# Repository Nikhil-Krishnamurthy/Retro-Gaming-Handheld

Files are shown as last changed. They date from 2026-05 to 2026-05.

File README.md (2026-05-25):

# Retro-Gaming-Handheld
This project was creating a gaming handheld from scratch, including cadding the case and designing the pcb. This handheld will run retro games up to the SNES.

Key Features
Esp32 powered emulation   
RGB444 7in screen    
Dedicated sound system    
Cold swappable storage system    
Rechargable 3500mAh battery    
USB C data transfer to computer    
USB C powered charging    

Schematic   

Power   


Buttons   


Screen   


Data   


Sound   


ESP 32   


PCB Layout   


Case   




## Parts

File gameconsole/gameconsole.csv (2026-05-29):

Reference | Qty | Value | DNP | Exclude from BOM | Exclude from Board | Footprint | Datasheet | Description_1 | MP
A_Button1,B_Button1,DOWN1,LEFT1,MENU1,RIGHT1,SELECT_Button1,START_Button1,SW1,SW2,UP1,X_Button1,Y_Button1 | 13 | PTS810 (250gf) |  |  |  | PTS810_SJM_250_SMTR_LFS:SW_PTS810_SJM_250_SMTR_LFS |  | Tactile Switch, SPST-NO, Top Actuated, Surface Mount (SMT), 2.5mm height, 0.15mm travel. Local equivalent OK, but must match footprint dimensions, SMT pad style, 160gf to 260gf of activiation force | PTS810_SJM_250_SMTR_LFS
C1,C3,C5,C8,C14,C15,C17,C19 | 8 | 10uF |  |  |  | CL31A106MBHNNNE:CAPC3216X180N |  | 10uF, 16V or higher, X7R, 1206
C2,C9,C10,C11,C12,C13,C16,C23,C24,C29 | 10 | 10nF |  |  |  | GRM1885C1H103JA01D:CAPC1608X90N |  | 10nF, 16V or higher, X7R, 0805
C4,C7,C20 | 3 | 100nF |  |  |  | CL10B104KB8NNNC:CAPC1608X90N |  | 100nF, 16V or higher, X7R, 0805
C6 | 1 | 0.47uF |  |  |  | CL10B474KA8NFNC:CAPC1608X90N |  | 0.47uF, 16V or higher, X7R, 0805
C18 | 1 | 0.047uF |  |  |  | Capacitor_SMD:C_0805_2012Metric_Pad1.18x1.45mm_HandSolder |  | 0.047uF, 16V or higher, X7R, 0805
C21,C22 | 2 | 4.7uF |  |  |  | CL31B475KAHNNNE:CAPC3216X180N |  | 4.7uF, 16V or higher, X7R, 1206
C25,C26 | 2 | 47uF |  |  |  | C3216X5R1E476M160AC:CAPC3216X180N |  | 47uF, 16V or higher, X5R, 1206
C27 | 1 | 1000pF |  |  |  | Capacitor_SMD:C_0805_2012Metric_Pad1.18x1.45mm_HandSolder |  | 1000pF, 16V or higher, C0G, 0805
C28 | 1 | 47pF |  |  |  | Capacitor_SMD:C_0805_2012Metric_Pad1.18x1.45mm_HandSolder |  | 47pF, 16v or higher, C0G, 0805
D1 | 1 | MBR0520LT1G |  |  |  | MBR0520LT1G:SOD3716X135N |  | Local Equivalent OK. Diode Schottky 20 V 500mA Surface Mount SOD-123 | MBR0520LT1G
D2 | 1 | B340A |  |  |  | B340AE-13:DIOM5226X230N |  | Local Equivalent OK. Must be SMA package. | B340AE-13
IHLP1616BZER4R7M11 | 1 | 4.7uH |  |  |  | ul_IHLP1616BZER4R7M11:IND_IHLP-1616BZ_VIS |  | Local Equivalent OK, 4.7uH, 20% tolerance or higher, 1.75 lsat, shielded | IHLP1616BZER4R7M11
J1 | 1 | 62684-401100ALF |  |  |  | 62684-401100ALF:CONN_62684-401100ALF_AMP | 62684-401100ALF | Local Equivalent OK, bottom contacts, 40 position, 0.50mm pitch | 62684-401100ALF
J2 | 1 | USB4216-03-A_REVA |  |  |  | USB4216-03-A_REVA:GCT_USB4216-03-A_REVA |  | Type C USB 2.0 Connector | USB4216-03-A
L2 | 1 | WE-MAPI_2512 |  |  |  | WE-MAPI_4020:WE-MAPI_4020 |  | WE-MAPI SMD Power Inductor 1.5uH 2.2A | Wurth Electronics 74438324015, local equivilent OK as long as electrical aspects and footprints are exactly the same | 74438324015
L3 | 1 | 6.8uH |  |  |  | LIB_BMRA000606306R8MA1:INDPM7366X300N |  | Shielded Molded Power Inductor, 6.8uH, ±20%, 4.5A Irms, 8.0A Isat, 60mOhm max DCR, SMD, 7.3mm x 6.6mm x 3.0mm. Local equivalent OK if all electrical and footprint dimensions match exactly. | BMRA000606306R8MA1
L_Button1,R_Button1,SW3,VOLDWN1,VOLUP1 | 5 | SW_Push |  |  |  | TL3330AF130QG:SW_TL3330AF130QG |  | Local Equivilent OK, 0.25mm switch travel, Right angle mount, SPST-NO, Gull Wing Leads, 130gf operating force
R1,R4,R5,R7,R8,R9,R10,R11,R12,R14,R17,R18,R19,R20,R30,R31,R32,R33,R34,R35,R36,R37,R38,R39,R40,R41,R43,R44,R45,R46,R47 | 31 | 10k |  |  |  | Resistor_SMD:R_0805_2012Metric_Pad1.20x1.40mm_HandSolder |  | 10k, 5% or tighter, 1/8W or higher, 0805
R2,R3 | 2 | EXB-2HV330JV |  |  |  | EXB-2HV330JV:RESCAXE50P380X160X55-16N | EXB-2HV330JV | Thick Film Resistor Array, 33 Ohm, ±5%, 8 Resistors (Isolated Circuit), 16-Pins, Convex Long Side Terminals, 62.5mW per element, 1506 package (3.80mm x 1.60mm). Local equivalent OK but must match footprint, pitch, and isolated circuit structure exactly. | EXB-2HV330JV
R6 | 1 | 1.43 |  |  |  | Resistor_SMD:R_0805_2012Metric_Pad1.20x1.40mm_HandSolder |  | 1.43, 1% or tighter, 1/8W or higher, 0805
R13 | 1 | 634k |  |  |  | Resistor_SMD:R_0805_2012Metric_Pad1.20x1.40mm_HandSolder |  | 634k, 1% or tighter, 1/8W or higher, 0805
R15,R16 | 2 | 5.1k |  |  |  | Resistor_SMD:R_0805_2012Metric_Pad1.20x1.40mm_HandSolder |  | 5.1k, 5% or tighter, 1/8W or higher, 0805
R21 | 1 | 240 |  |  |  | Resistor_SMD:R_0805_2012Metric_Pad1.20x1.40mm_HandSolder |  | 240, 1% or tighter, 1/8W or higher, 0805
R22 | 1 | 5.21K |  |  |  | Resistor_SMD:R_0805_2012Metric_Pad1.20x1.40mm_HandSolder |  | 5.21k, 1% or tighter, 1/8W or higher, 0805
R23 | 1 | 29.87k |  |  |  | Resistor_SMD:R_0805_2012Metric_Pad1.20x1.40mm_HandSolder |  | 29.87k, 1% or tighter, 1/8W or higher, 0805
R24 | 1 | 165k |  |  |  | Resistor_SMD:R_0805_2012Metric_Pad1.20x1.40mm_HandSolder |  | 165k, 5% or tighter, 1/8W or higher, 0805
R25 | 1 | 60.4k |  |  |  | Resistor_SMD:R_0805_2012Metric_Pad1.20x1.40mm_HandSolder |  | 60.4k, 5% or tighter, 1/8W or higher, 0805
R26 | 1 | 0 |  |  |  | Resistor_SMD:R_0805_2012Metric_Pad1.20x1.40mm_HandSolder |  | Resistor, 0 Ohm Jumper, 2A minimum current rating, 0805
R27 | 1 | 10.2k |  |  |  | Resistor_SMD:R_0805_2012Metric_Pad1.20x1.40mm_HandSolder |  | 10.2k, 1% or tighter, 1/8W or higher, 0805
R28 | 1 | 3.24k |  |  |  | Resistor_SMD:R_0805_2012Metric_Pad1.20x1.40mm_HandSolder |  | 3.24k, 1% or tighter, 1/8W or higher, 0805
R29 | 1 | 29.4k |  |  |  | Resistor_SMD:R_0805_2012Metric_Pad1.20x1.40mm_HandSolder |  | 29.4k, 1% or tighter, 1/8W or higher, 0805
U1 | 1 | ESP32-S3-WROOM-1 |  |  |  | RF_Module:ESP32-S3-WROOM-1 | https://www.espressif.com/sites/default/files/documentation/esp32-s3-wroom-1_wroom-1u_datasheet_en.pdf | Wi-Fi + BT 5.0 Module, ESP32-S3 chip, 16MB Quad SPI Flash, 8MB Octal SPI PSRAM, PCB Antenna. Must be exact MPN, no substitutions. | ESP32-S3-WROOM-1-N16R8
U2 | 1 | BQ25895RTWR |  |  |  | BQ25895RTWR:QFN50P400X400X80-25N |  | I2C 1cell 5A buck battery charger with high input voltage and 3.1-A boost with HVDCP enabled | BQ25895RTWR
U3 | 1 | MP3302DJ-LF-Z |  |  |  | MP3302DJ-LF-Z:TSOT23-5_3x3x1p7_MNP | https://www.monolithicpower.com/en/documentview/productdocument/index/version/2/document_type/Datasheet/lang/en/sku/MP3302 | Step-Up Boost Converter, LED Backlight Driver, 200mV Feedback Reference Voltage, 1.33A Switch Current Limit, TSOT-23-5. Local Equivalent OK but must match pinning and 200mV FB reference voltage exactly. | MP3302DJ-LF-Z
U4 | 1 | TCA6424ARGJR |  |  |  | TCA6424ARGJR:QFN50P500X500X60-33N |  | 24-bit translating 1.65- to 5.5-V I2C/SMBus I/O expander with interrupt, reset & config registers | TCA6424ARGJR
U5 | 1 | MAX98357AETE_T |  |  |  | MAX98357AETE_T:QFN50P300X300X80-17N |  | Tiny, Low-Cost, PCM Class D Amplifier with Class AB Performance | MAX98357AETE+T
U7 | 1 | TPS54331DR |  |  |  | TPS54331DR:SOIC127P599X175-8N |  | 3.5V to 28V Input, 3A, 570kHz Step-Down Converter with Eco-mode | TPS54331DR
J3 | 1 | NTCLE413E2103F520L | DNP |  | Excluded from board | S2B-PH-K-S_LF__SN_:JST_S2B-PH-K-S_LF__SN_
J4 | 1 | S2B-PH-K-S_LF__SN_ | DNP |  | Excluded from board | S2B-PH-K-S_LF__SN_:JST_S2B-PH-K-S_LF__SN_ |  | Connector Header Through Hole, Right Angle 2 position 0.079 (2.00mm) | S2B-PH-K-S (LF)(SN)
J5 | 1 | S2B-XH-A_LF__SN_ | DNP |  | Excluded from board | S2B-XH-A_LF__SN_:JST_S2B-XH-A_LF__SN_ |  | Connector Header Through Hole, Right Angle 2 position 0.098 (2.50mm) | S2B-XH-A (LF)(SN)
SDREADER1 | 1 | Conn_01x07_Pin | DNP |  | Excluded from board | Connector_PinHeader_2.54mm:PinHeader_1x07_P2.54mm_Vertical

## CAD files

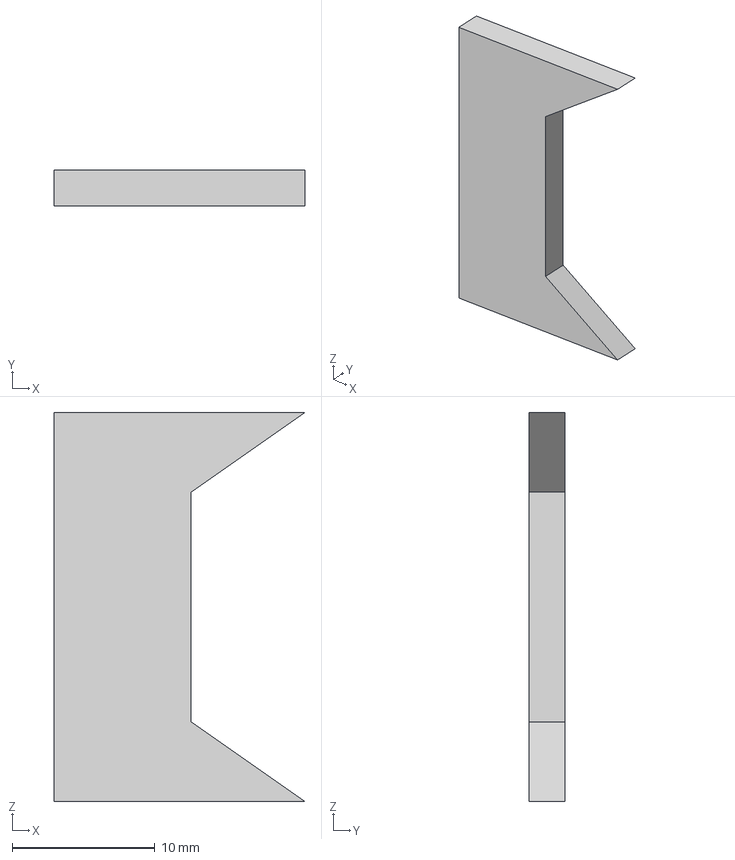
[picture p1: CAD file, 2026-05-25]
CAD/Case/topRightJoint.step
17.6 x 2.50 x 27.3 mm

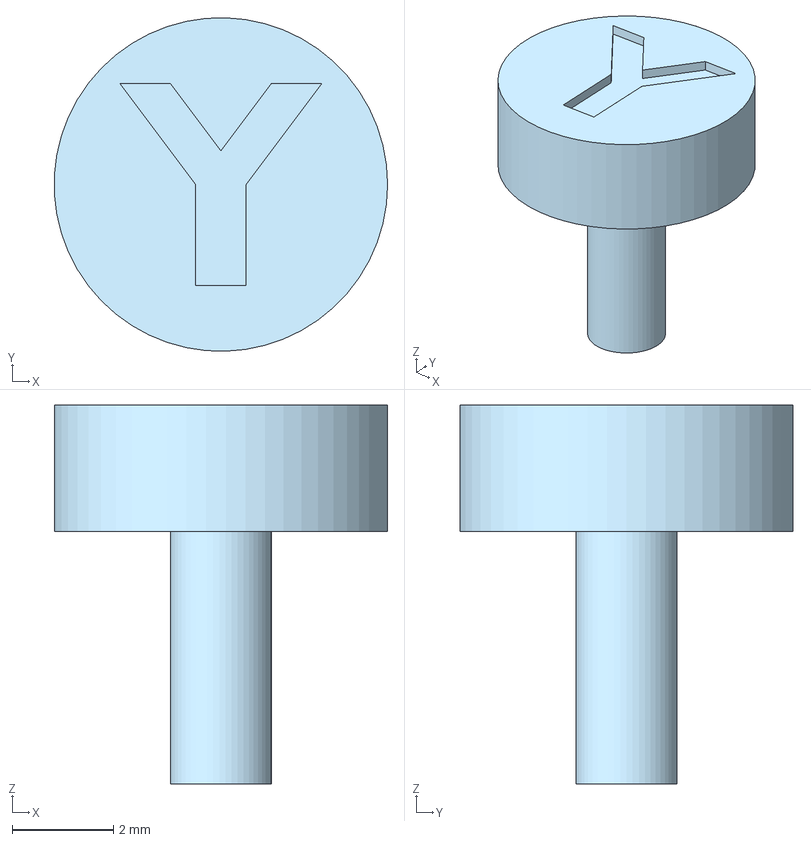
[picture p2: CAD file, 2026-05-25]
CAD/FrontButtons/YCap.step
6.59 x 6.60 x 7.50 mm

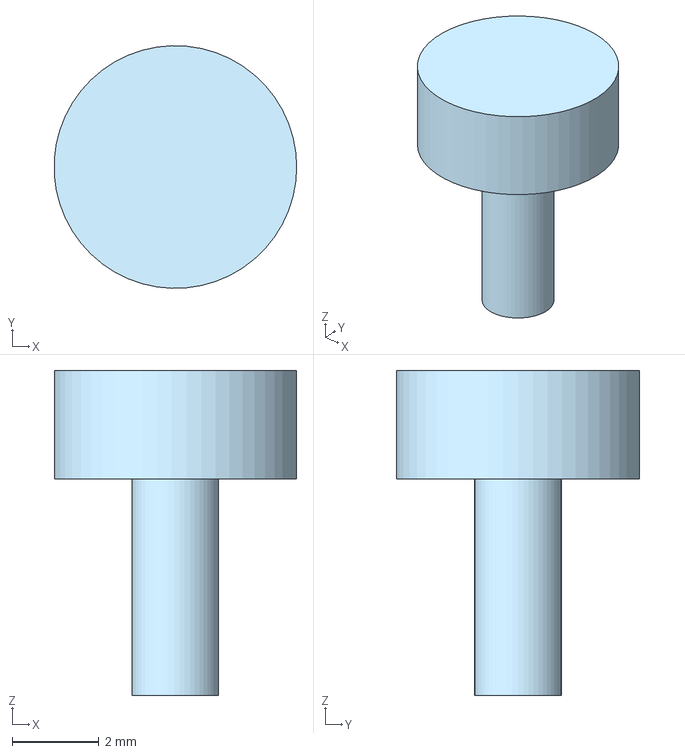
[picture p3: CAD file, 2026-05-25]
CAD/MenuButtons/MenuButtonCap.step
5.59 x 5.60 x 7.50 mm

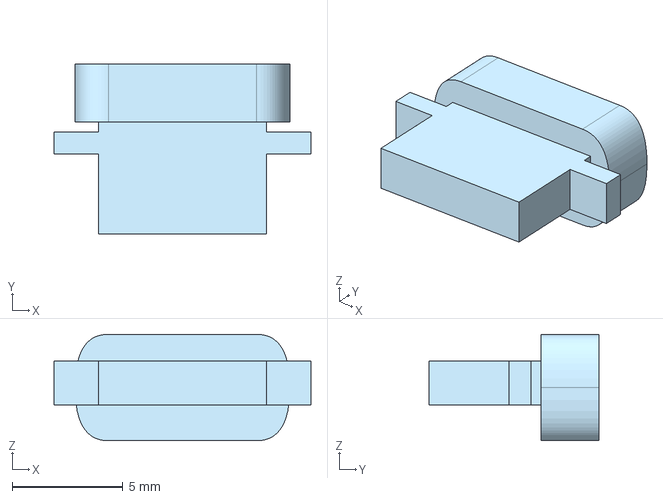
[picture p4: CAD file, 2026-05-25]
CAD/SideButtons/SidePlunger.step
11.6 x 7.68 x 4.80 mm

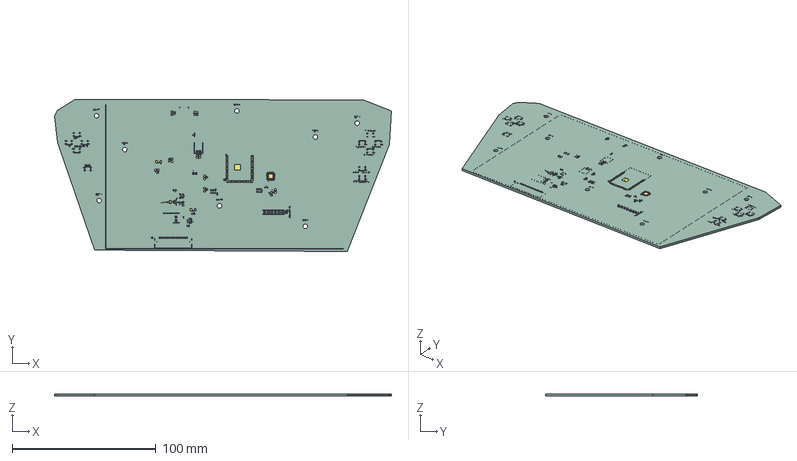
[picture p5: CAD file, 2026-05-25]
gameconsole/case.step
234.1 x 105.6 x 1.66 mm
GameConsoleTransportv2_pad
GameConsoleTransportv2_silkscreen x 2
GameConsoleTransportv2_PCB

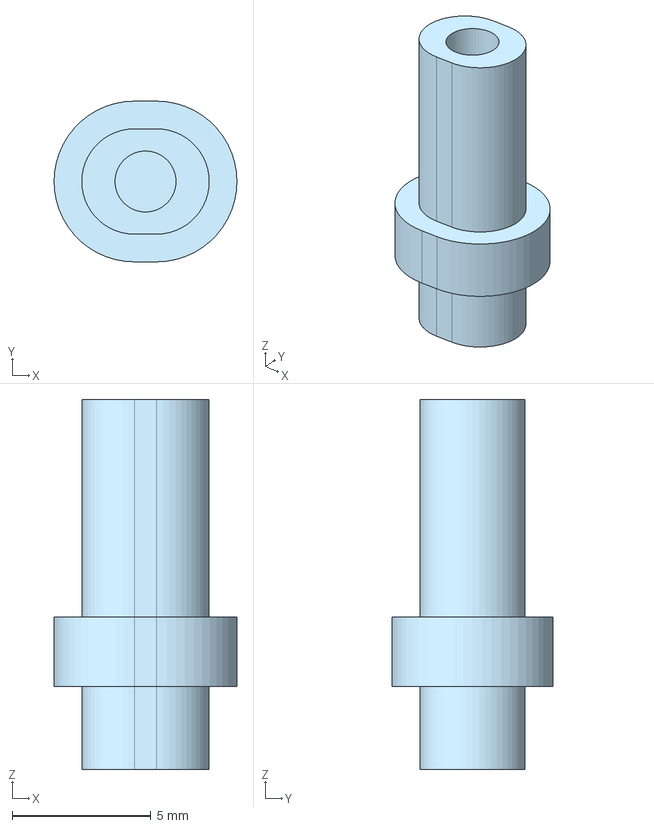
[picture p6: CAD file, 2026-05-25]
CAD/MenuButtons/MenuButtonShaft.step
6.60 x 5.80 x 13.4 mm

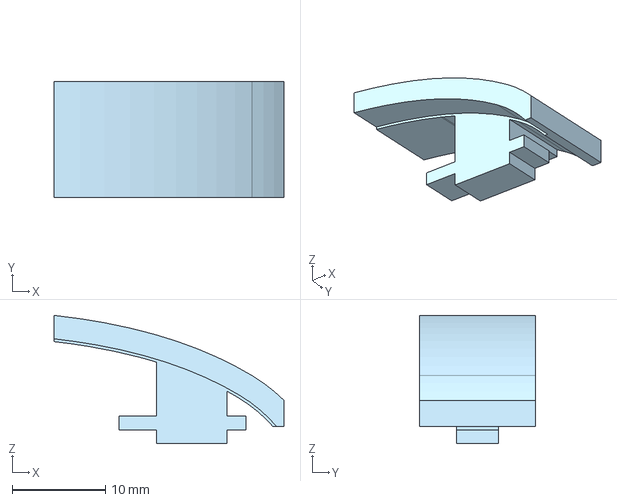
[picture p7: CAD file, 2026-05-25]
CAD/SideButtons/RightPlunger.step
24.7 x 12.5 x 13.8 mm

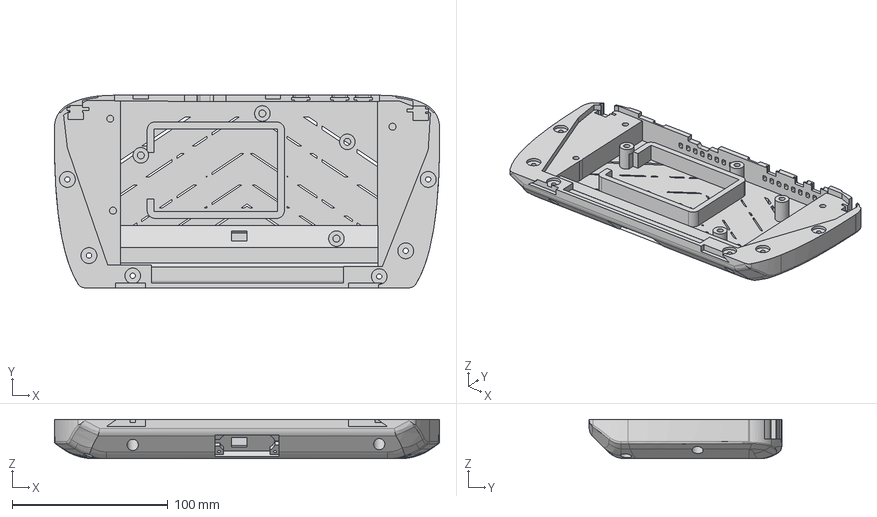
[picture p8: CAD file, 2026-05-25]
CAD/Case/backPanel.step
246.9 x 123.5 x 25.3 mm

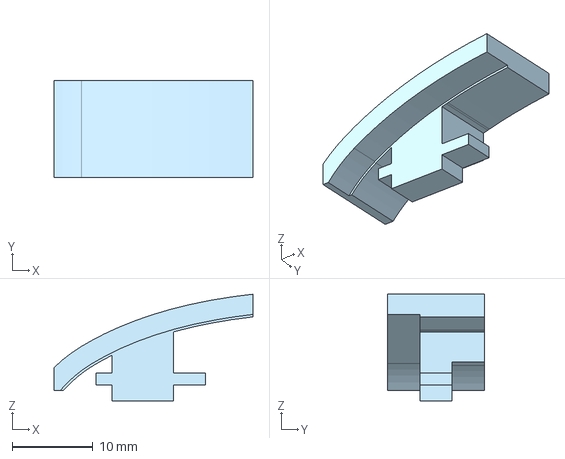
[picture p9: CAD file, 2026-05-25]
CAD/SideButtons/LeftPlunger.step
24.7 x 12.0 x 13.2 mm

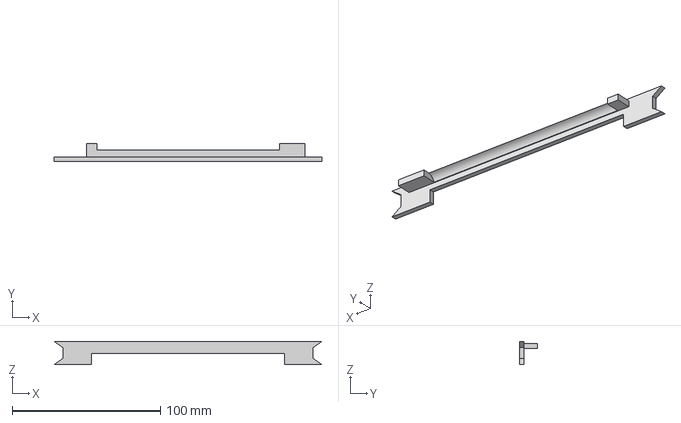
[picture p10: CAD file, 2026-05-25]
CAD/Case/bottomJoint.step
180.6 x 12.1 x 15.7 mm

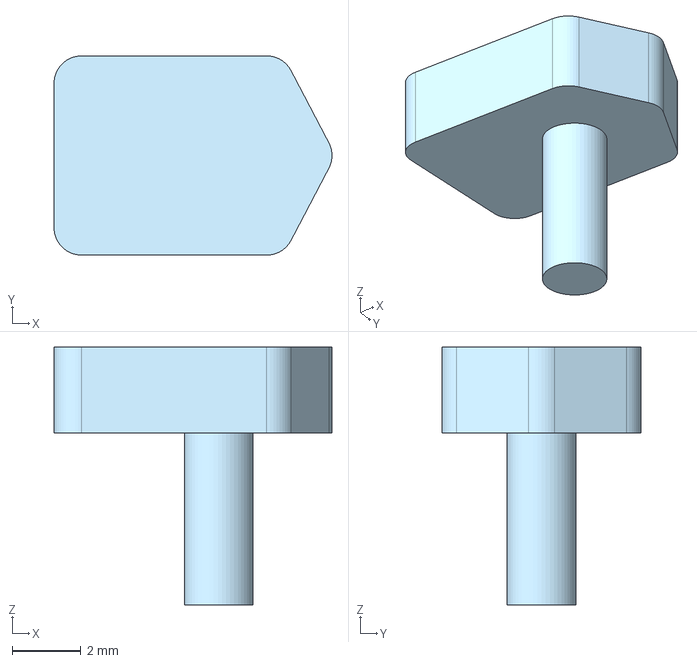
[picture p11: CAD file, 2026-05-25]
CAD/FrontButtons/DPADCap.step
8.10 x 5.80 x 7.50 mm

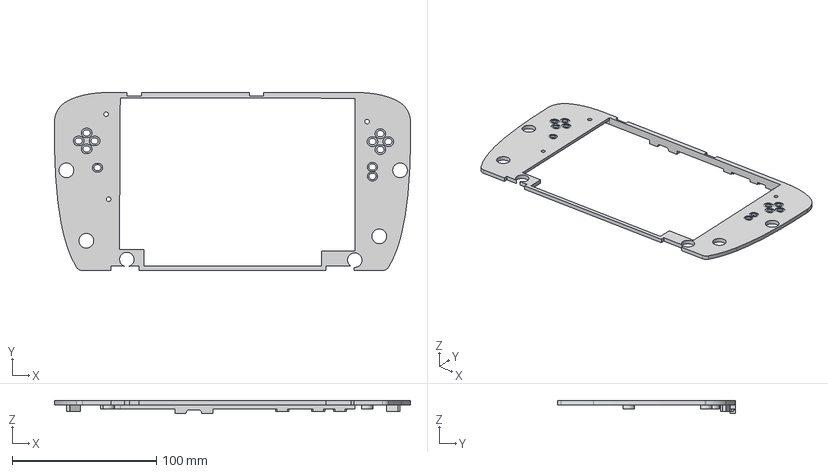
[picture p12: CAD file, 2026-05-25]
CAD/Case/middlePanel.step
246.9 x 123.5 x 8.93 mm

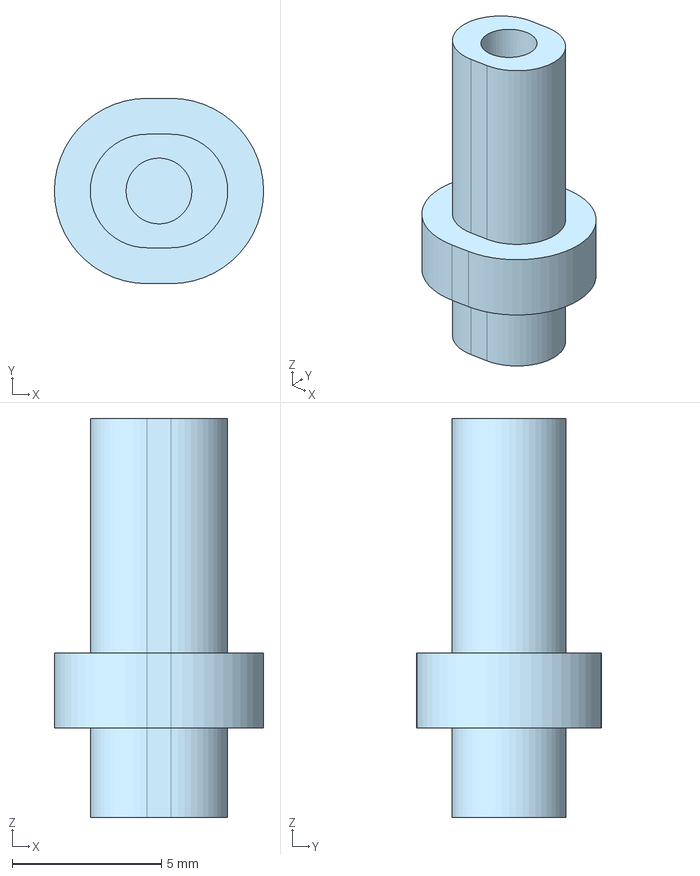
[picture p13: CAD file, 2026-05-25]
CAD/FrontButtons/FrontButtonShaft.step
7.00 x 6.20 x 13.4 mm

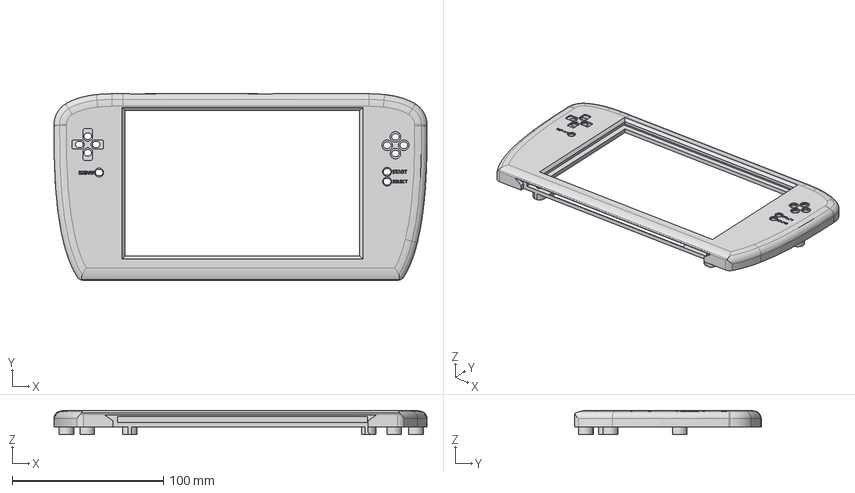
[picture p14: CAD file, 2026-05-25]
CAD/Case/frontPanel.step
246.9 x 123.5 x 16.0 mm

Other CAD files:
CAD/Case/topLeftJoint.step
CAD/FrontButtons/ACap.step
CAD/FrontButtons/XCap.step
CAD/FrontButtons/BCap.step

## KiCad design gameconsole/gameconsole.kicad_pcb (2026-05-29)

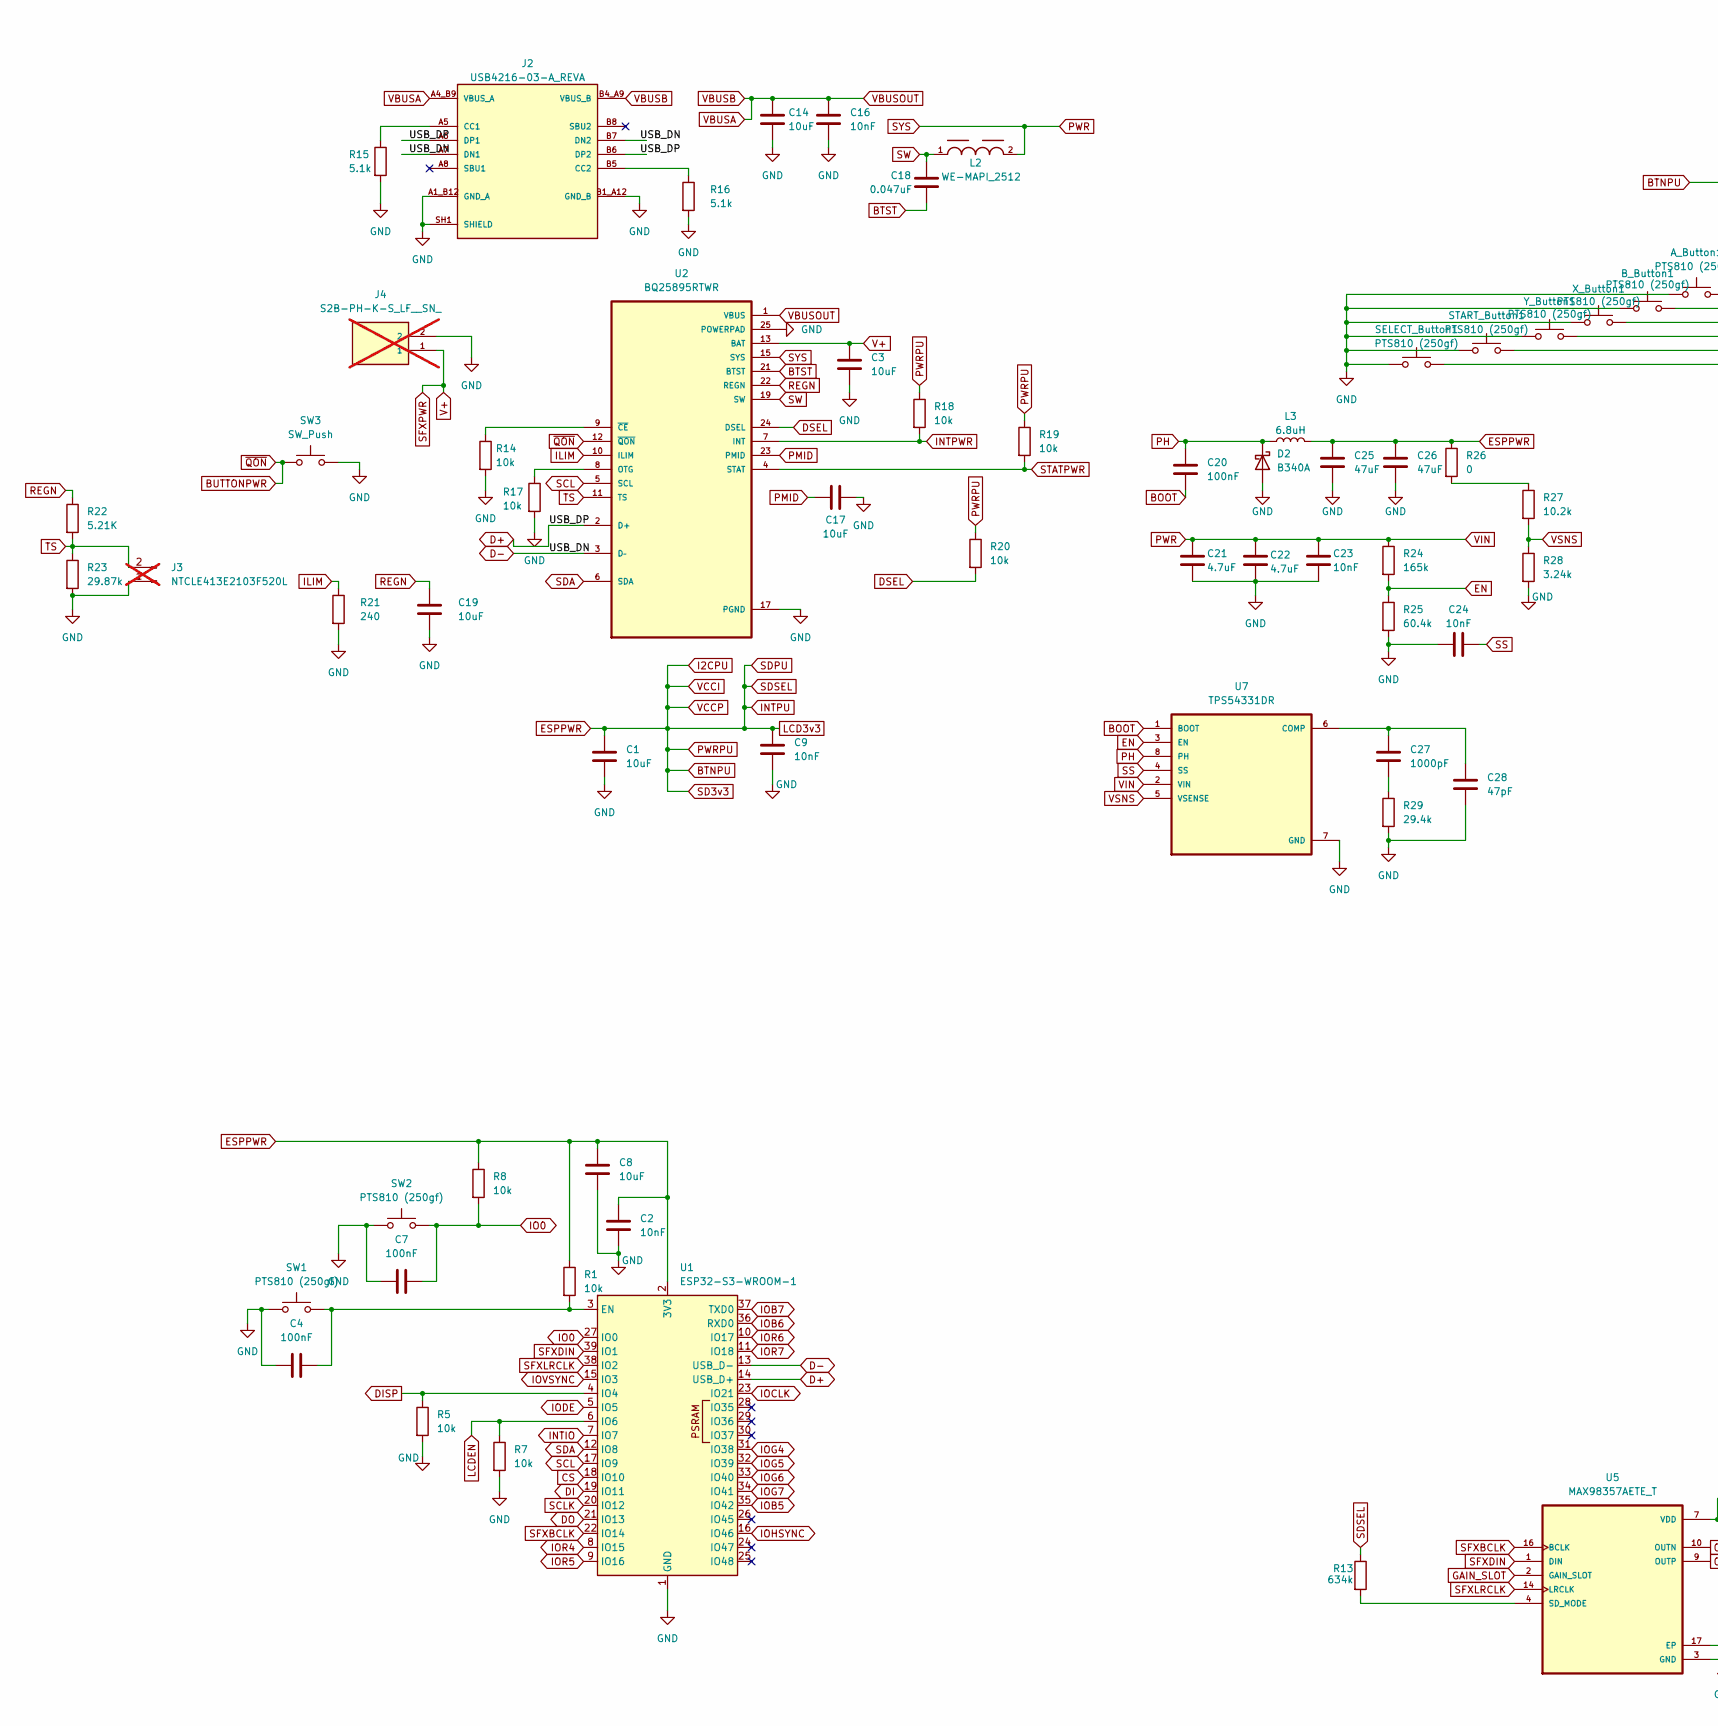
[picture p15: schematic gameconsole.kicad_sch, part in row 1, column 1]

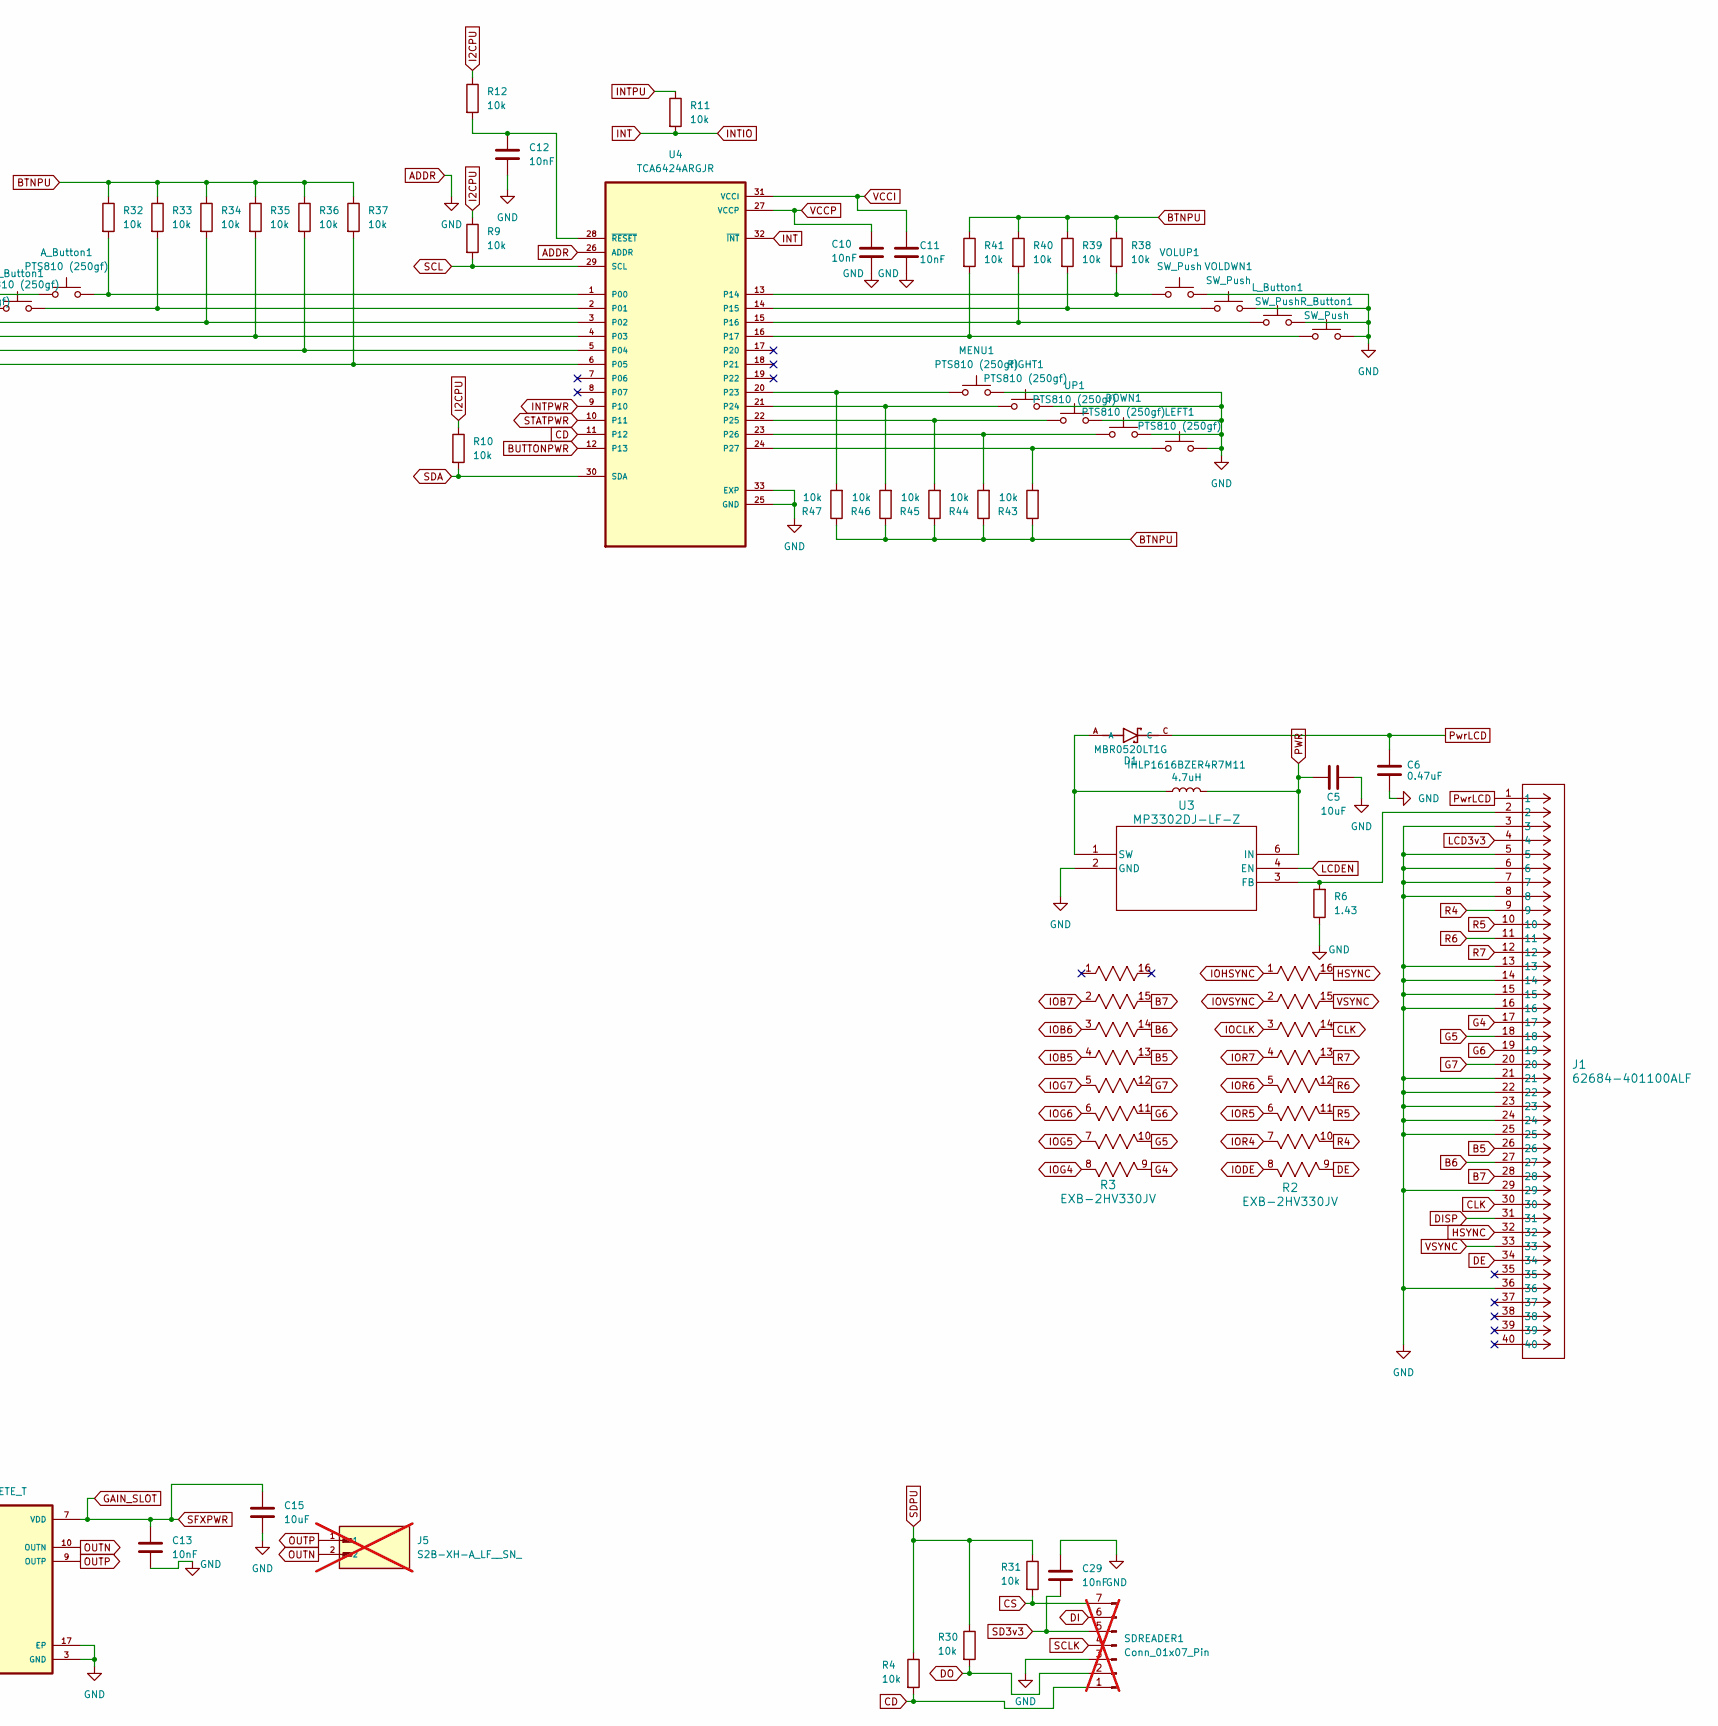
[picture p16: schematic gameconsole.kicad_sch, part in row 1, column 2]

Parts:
A_Button1: PTS810 (250gf); SW_PTS810_SJM_250_SMTR_LFS
B_Button1: PTS810 (250gf); SW_PTS810_SJM_250_SMTR_LFS
C1, C3, C5, C8, C14, C15, C17, C19: 10uF; CAPC3216X180N
C2, C9, C10, C11, C12, C13, C16, C23, C24, C29: 10nF; CAPC1608X90N
C4, C7, C20: 100nF; CAPC1608X90N
C6: 0.47uF; CAPC1608X90N
C18: 0.047uF; C_0805_2012Metric_Pad1.18x1.45mm_HandSolder
C21, C22: 4.7uF; CAPC3216X180N
C25, C26: 47uF; CAPC3216X180N
C27: 1000pF; C_0805_2012Metric_Pad1.18x1.45mm_HandSolder
C28: 47pF; C_0805_2012Metric_Pad1.18x1.45mm_HandSolder
D1: MBR0520LT1G; SOD3716X135N
D2: B340A; DIOM5226X230N
DOWN1: PTS810 (250gf); SW_PTS810_SJM_250_SMTR_LFS
IHLP1616BZER4R7M11: 4.7uH; IND_IHLP-1616BZ_VIS
J1: 62684-401100ALF; CONN_62684-401100ALF_AMP
J2: USB4216-03-A_REVA; GCT_USB4216-03-A_REVA; PARTREV A
J3: NTCLE413E2103F520L; JST_S2B-PH-K-S_LF__SN_; not fitted
J4: S2B-PH-K-S_LF__SN_; JST_S2B-PH-K-S_LF__SN_; not fitted
J5: S2B-XH-A_LF__SN_; JST_S2B-XH-A_LF__SN_; PARTREV 27-1-20; not fitted
L2: WE-MAPI_2512; WE-MAPI_4020
L3: 6.8uH; INDPM7366X300N
LEFT1: PTS810 (250gf); SW_PTS810_SJM_250_SMTR_LFS
L_Button1: SW_Push; SW_TL3330AF130QG
MENU1: PTS810 (250gf); SW_PTS810_SJM_250_SMTR_LFS
R1, R4, R5, R7, R8, R9, R10, R11, R12, R14, R17, R18, R19, R20, R30, R31, R32, R33, R34, R35, R36, R37, R38, R39, R40, R41, R43, R44, R45, R46, R47: 10k; R_0805_2012Metric_Pad1.20x1.40mm_HandSolder
R2, R3: EXB-2HV330JV; RESCAXE50P380X160X55-16N
R6: 1.43; R_0805_2012Metric_Pad1.20x1.40mm_HandSolder
R13: 634k; R_0805_2012Metric_Pad1.20x1.40mm_HandSolder
R15, R16: 5.1k; R_0805_2012Metric_Pad1.20x1.40mm_HandSolder
R21: 240; R_0805_2012Metric_Pad1.20x1.40mm_HandSolder
R22: 5.21K; R_0805_2012Metric_Pad1.20x1.40mm_HandSolder
R23: 29.87k; R_0805_2012Metric_Pad1.20x1.40mm_HandSolder
R24: 165k; R_0805_2012Metric_Pad1.20x1.40mm_HandSolder
R25: 60.4k; R_0805_2012Metric_Pad1.20x1.40mm_HandSolder
R26: 0; R_0805_2012Metric_Pad1.20x1.40mm_HandSolder
R27: 10.2k; R_0805_2012Metric_Pad1.20x1.40mm_HandSolder
R28: 3.24k; R_0805_2012Metric_Pad1.20x1.40mm_HandSolder
R29: 29.4k; R_0805_2012Metric_Pad1.20x1.40mm_HandSolder
RIGHT1: PTS810 (250gf); SW_PTS810_SJM_250_SMTR_LFS
R_Button1: SW_Push; SW_TL3330AF130QG
SDREADER1: Conn_01x07_Pin; PinHeader_1x07_P2.54mm_Vertical; not fitted
SELECT_Button1: PTS810 (250gf); SW_PTS810_SJM_250_SMTR_LFS
START_Button1: PTS810 (250gf); SW_PTS810_SJM_250_SMTR_LFS
SW1, SW2: PTS810 (250gf); SW_PTS810_SJM_250_SMTR_LFS
SW3: SW_Push; SW_TL3330AF130QG
U1: ESP32-S3-WROOM-1
U2: BQ25895RTWR; QFN50P400X400X80-25N
U3: MP3302DJ-LF-Z; TSOT23-5_3x3x1p7_MNP
U4: TCA6424ARGJR; QFN50P500X500X60-33N
U5: MAX98357AETE_T; QFN50P300X300X80-17N
U7: TPS54331DR; SOIC127P599X175-8N
UP1: PTS810 (250gf); SW_PTS810_SJM_250_SMTR_LFS
VOLDWN1: SW_Push; SW_TL3330AF130QG
VOLUP1: SW_Push; SW_TL3330AF130QG
X_Button1: PTS810 (250gf); SW_PTS810_SJM_250_SMTR_LFS
Y_Button1: PTS810 (250gf); SW_PTS810_SJM_250_SMTR_LFS

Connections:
ADDR: A_Button1.1, B_Button1.1, C1.2, C2.2, C3.2, C4.2, C5.2, C6.2, C7.2, C8.2, C9.2, C10.2, C11.2, C12.2, C13.2, C14.2, C15.2, C16.2, C17.2, C19.2, C21.2, C22.2, C23.2, C24.1, C25.2, C26.2, C28.2, C29.1, D2.2 (A), DOWN1.2, J1.3, J1.5, J1.6, J1.7, J1.8, J1.13, J1.14, J1.15, J1.16, J1.21, J1.22, J1.23, J1.24, J1.25, J1.29, J1.36, J2.A1_B12 (GND_A), J2.B1_A12 (GND_B), J2.SH1 (SHIELD), J2.SH2 (SHIELD), J2.SH3 (SHIELD), J2.SH4 (SHIELD), J3.1, J4.2, LEFT1.2, L_Button1.2, MENU1.2, R5.2, R6.1, R7.2, R14.2, R15.2, R16.2, R17.2, R21.2, R23.2, R25.2, R28.2, R29.2, RIGHT1.2, R_Button1.2, SDREADER1.3, SELECT_Button1.1, START_Button1.1, SW1.1, SW2.1, SW3.2, U1.1 (GND), U1.40 (GND), U1.41 (GND), U2.17 (PGND), U2.18 (PGND), U2.25 (POWERPAD), U3.2 (GND), U4.25 (GND), U4.26 (ADDR), U4.33 (EXP), U5.3 (GND), U5.11 (GND), U5.15 (GND), U5.17 (EP), U7.7 (GND), UP1.2, VOLDWN1.2, VOLUP1.2, X_Button1.1, Y_Button1.1
B5: J1.26, R3.13
B6: J1.27, R3.14
B7: J1.28, R3.15
BOOT: C20.2, U7.1 (BOOT)
BTNPU: C1.1, C2.1, C8.1, C9.1, C10.1, C11.1, C25.1, C26.1, C29.2, J1.4, L3.2, R1.1, R4.1, R8.1, R9.1, R10.1, R11.1, R12.1, R13.1, R18.1, R19.1, R20.1, R26.1, R30.1, R31.1, R32.1, R33.1, R34.1, R35.1, R36.1, R37.1, R38.1, R39.1, R40.1, R41.1, R43.1, R44.1, R45.1, R46.1, R47.1, SDREADER1.5, U1.2 (3V3), U4.27 (VCCP), U4.31 (VCCI)
BTST: C18.2, U2.21 (BTST)
BUTTONPWR: SW3.1, U2.12 (~QON), U4.12 (P13)
CD: R4.2, SDREADER1.1, U4.11 (P12)
CLK: J1.30, R2.14
CS: R31.2, SDREADER1.7, U1.18 (IO10)
D+: J2.A6 (DP1), J2.B6 (DP2), U1.14 (USB_D+), U2.2 (D+)
D-: J2.A7 (DN1), J2.B7 (DN2), U1.13 (USB_D-), U2.3 (D–)
DE: J1.34, R2.9
DI: SDREADER1.6, U1.19 (IO11)
DISP: J1.31, R5.1, U1.4 (IO4)
DO: R30.2, SDREADER1.2, U1.21 (IO13)
DSEL: R20.2, U2.24 (DSEL)
EN: R24.2, R25.1, U7.3 (EN)
G4: J1.17, R3.9
G5: J1.18, R3.10
G6: J1.19, R3.11
G7: J1.20, R3.12
GAIN_SLOT: C3.1, C13.1, C15.1, J4.1, U2.13 (BAT), U2.14 (BAT), U5.2 (GAIN_SLOT), U5.7 (VDD), U5.8 (VDD)
HSYNC: J1.32, R2.16
ILIM: R21.1, U2.10 (ILIM)
INT: R11.2, U1.7 (IO7), U4.32 (~INT)
INTPWR: R18.2, U2.7 (INT), U4.9 (P10)
IO0: C7.1, R8.2, SW2.2, U1.27 (IO0)
IOB5: R3.4, U1.35 (IO42)
IOB6: R3.3, U1.36 (RXD0)
IOB7: R3.2, U1.37 (TXD0)
IOCLK: R2.3, U1.23 (IO21)
IODE: R2.8, U1.5 (IO5)
IOG4: R3.8, U1.31 (IO38)
IOG5: R3.7, U1.32 (IO39)
IOG6: R3.6, U1.33 (IO40)
IOG7: R3.5, U1.34 (IO41)
IOHSYNC: R2.1, U1.16 (IO46)
IOR4: R2.7, U1.8 (IO15)
IOR5: R2.6, U1.9 (IO16)
IOR6: R2.5, U1.10 (IO17)
IOR7: R2.4, U1.11 (IO18)
IOVSYNC: R2.2, U1.15 (IO3)
LCDEN: R7.1, U1.6 (IO6), U3.4 (EN)
unnamed: C27.2, R29.1
unnamed: J2.A5 (CC1), R15.1
unnamed: J2.B5 (CC2), R16.1
unnamed: R26.2, R27.1
unnamed: C4.1, R1.2, SW1.2, U1.3 (EN)
unnamed: R17.1, U2.8 (OTG)
unnamed: R14.1, U2.9 (~CE)
unnamed: J1.2, R6.2, U3.3 (FB)
unnamed: D1.A, IHLP1616BZER4R7M11.1, U3.1 (SW)
unnamed: A_Button1.2, R32.2, U4.1 (P00)
unnamed: B_Button1.2, R33.2, U4.2 (P01)
unnamed: R34.2, U4.3 (P02), X_Button1.2
unnamed: R35.2, U4.4 (P03), Y_Button1.2
unnamed: R36.2, START_Button1.2, U4.5 (P04)
unnamed: R37.2, SELECT_Button1.2, U4.6 (P05)
unnamed: R38.2, U4.13 (P14), VOLUP1.1
unnamed: R39.2, U4.14 (P15), VOLDWN1.1
unnamed: L_Button1.1, R40.2, U4.15 (P16)
unnamed: R41.2, R_Button1.1, U4.16 (P17)
unnamed: MENU1.1, R47.2, U4.20 (P23)
unnamed: R46.2, RIGHT1.1, U4.21 (P24)
unnamed: R45.2, U4.22 (P25), UP1.1
unnamed: DOWN1.1, R44.2, U4.23 (P26)
unnamed: LEFT1.1, R43.2, U4.24 (P27)
unnamed: C12.1, R12.2, U4.28 (~RESET)
unnamed: R13.2, U5.4 (SD_MODE)
unnamed: C27.1, C28.1, U7.6 (COMP)
OUTN: J5.2, U5.10 (OUTN)
OUTP: J5.1, U5.9 (OUTP)
PH: C20.1, D2.1 (K), L3.1, U7.8 (PH)
PMID: C17.1, U2.23 (PMID)
PWR: C5.1, C21.1, C22.1, C23.1, IHLP1616BZER4R7M11.2, L2.2, R24.1, U2.15 (SYS), U2.16 (SYS), U3.6 (IN), U7.2 (VIN)
PwrLCD: C6.1, D1.C, J1.1
R4: J1.9, R2.10
R5: J1.10, R2.11
R6: J1.11, R2.12
R7: J1.12, R2.13
REGN: C19.1, R22.1, U2.22 (REGN)
SCL: R9.2, U1.17 (IO9), U2.5 (SCL), U4.29 (SCL)
SCLK: SDREADER1.4, U1.20 (IO12)
SDA: R10.2, U1.12 (IO8), U2.6 (SDA), U4.30 (SDA)
SFXBCLK: U1.22 (IO14), U5.16 (BCLK)
SFXDIN: U1.39 (IO1), U5.1 (DIN)
SFXLRCLK: U1.38 (IO2), U5.14 (LRCLK)
SS: C24.2, U7.4 (SS)
STATPWR: R19.2, U2.4 (STAT), U4.10 (P11)
SW: C18.1, L2.1, U2.19 (SW), U2.20 (SW)
TS: J3.2, R22.2, R23.1, U2.11 (TS)
VBUSA: C14.1, C16.1, J2.A4_B9 (VBUS_A), J2.B4_A9 (VBUS_B), U2.1 (VBUS)
VSNS: R27.2, R28.1, U7.5 (VSENSE)
VSYNC: J1.33, R2.15

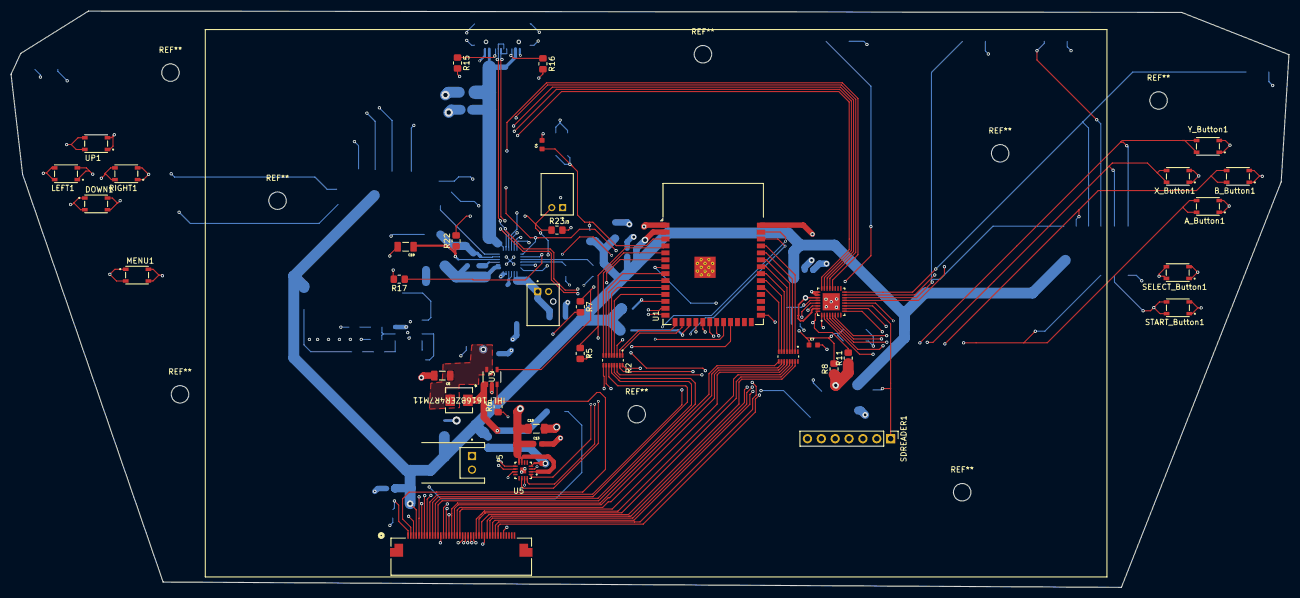
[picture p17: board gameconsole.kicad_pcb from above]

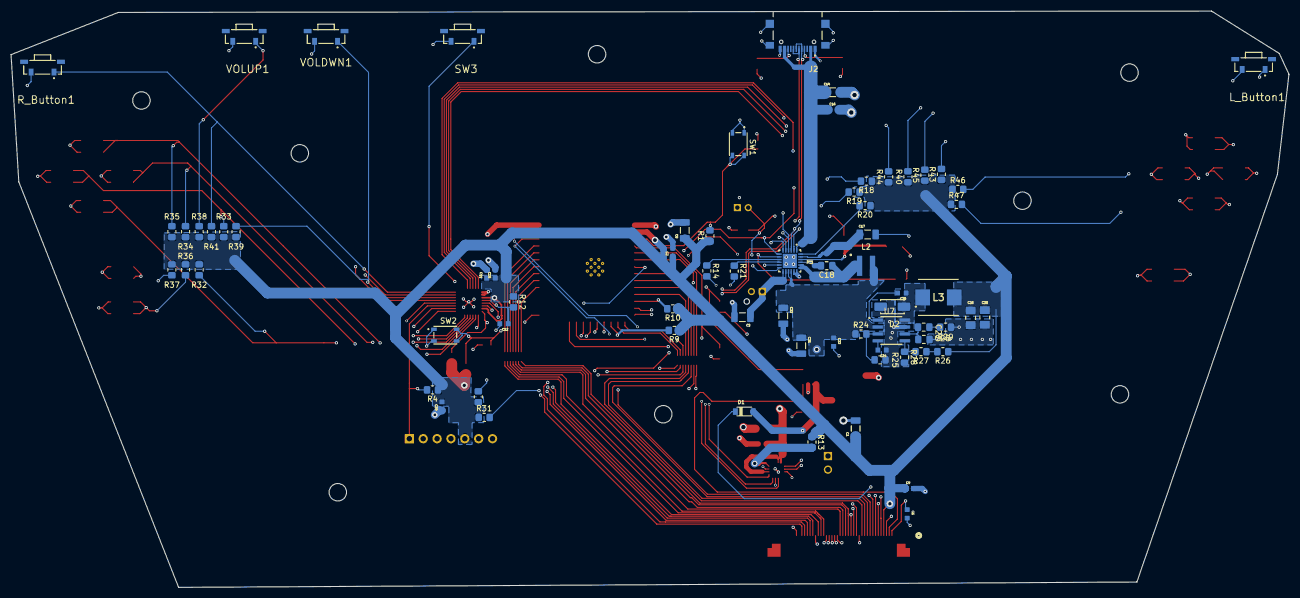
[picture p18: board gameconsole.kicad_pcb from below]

Board: 4 copper layers, 234.1 x 105.6 mm, 110 parts (71 on the bottom side), 96 nets.

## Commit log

2026-05-25 PCB files
    [case.step, gameconsole.kicad_pcb, gameconsole.kicad_sch]
2026-05-25 Cad Files
    [ACap.step, BCap.step, DPADCap.step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]
2026-05-29 Revised Gameconsole kicad schematic
    [gameconsole.kicad_pcb]
2026-05-29 PCB Drawings
    [gameconsole.csv, gameconsole.kicad_pcb, gameconsole.kicad_sch]
